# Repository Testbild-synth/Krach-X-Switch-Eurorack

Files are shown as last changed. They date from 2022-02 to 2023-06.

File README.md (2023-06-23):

# Krach X-Switch Eurorack Performance Module

Recently, I was commissioned by [Krach der Roboter](https://www.facebook.com/KrachDerRoboter/) who had the idea to design a passive performance tool based on the idea of quickly switching signal paths. What came out of it is this simple and useful module:

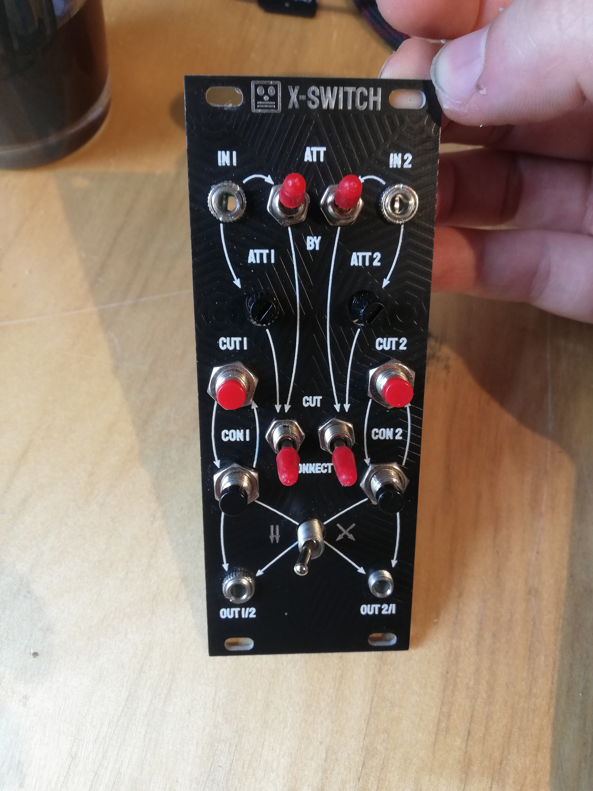
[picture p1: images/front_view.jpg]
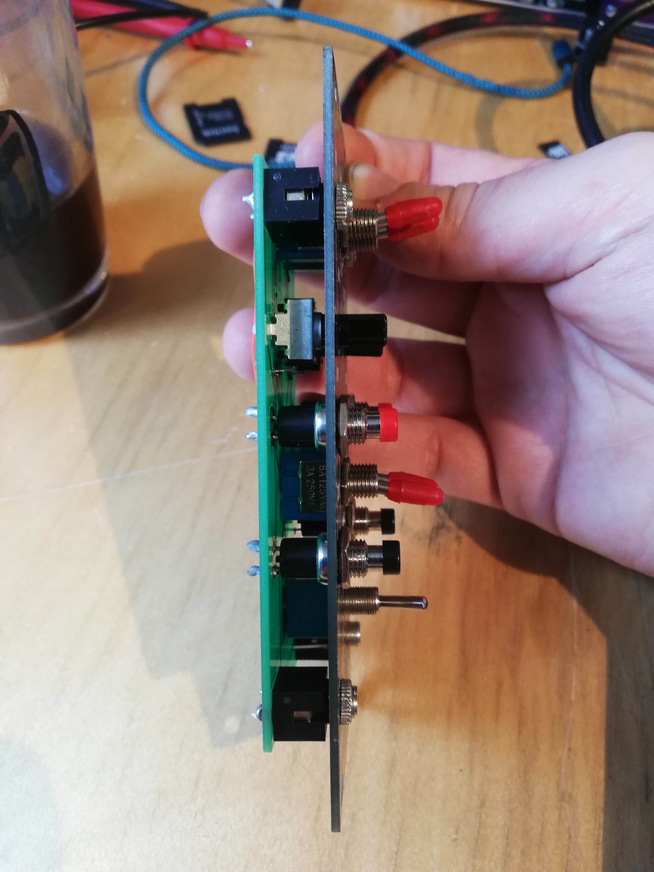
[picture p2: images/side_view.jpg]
 

## Status: recently added version 1.3 which has improved spacing for cut/connect switch legs

## Function

The core function of the module revolves around the "cross-switch". Two input channels are attenuated independently and then go to the output, but if you flip the cross switch, the Input 1 goes into output 2 and vice versa. This allows for fast back and forth switching of cv signals.
Additional pushbuttons can be used to cut or connect a lane. Spacing between components is rather large to allow his robot hands to reach everything easily.

This is also meant as an absolute beginner/first DIY module, so everything is made to be very easy to solder and all the traces are rather large so nothing gets damaged.

## PCB and Hardware

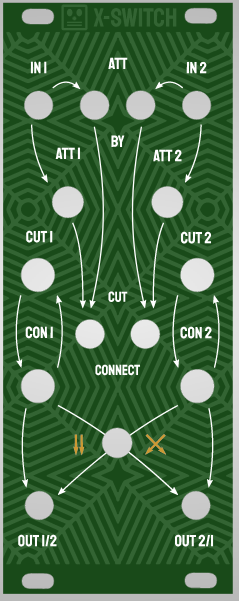
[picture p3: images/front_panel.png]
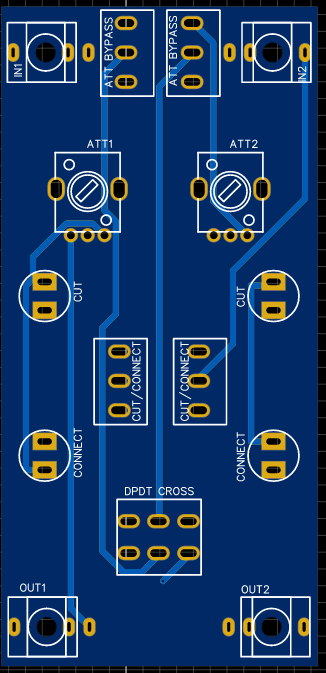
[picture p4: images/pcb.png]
 

You can find the schematic and BOM in the root folder.
For the PCBs, the module has one circuit PCB and one panel PCB. 
You can order them on any common PCB manufacturing service, we used [JLCPCB](https://jlcpcb.com/).

Standard settings should be fine, but as there is exposed copper on the panel you should go with a lead free surface finish (ENIG/Leadfree HASL).
If the panel sizes are not recognized correctly (may happen with my export sometimes) just put 128.5x50mm.

For the push switches, we used these, but you can use any that will somewhat fit the footprint and have <m7 thread on the top.
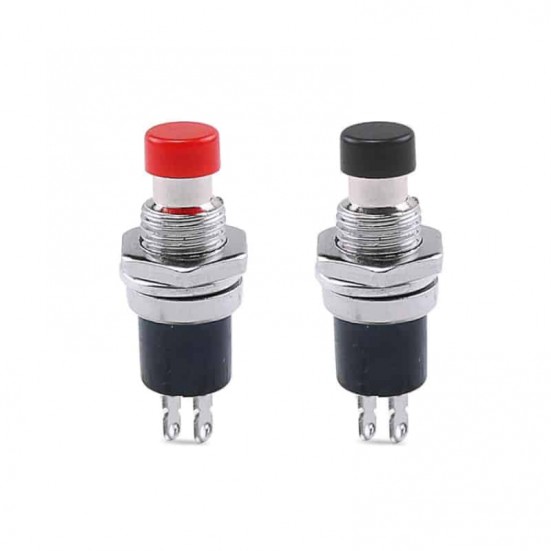
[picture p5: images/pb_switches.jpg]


## Assembly
Should be very straight forward, as always it is best to mount the components on the panel first before soldering so that they are properly in place.

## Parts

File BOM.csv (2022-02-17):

Name | Designator | Quantity
R09k Potentiometer, 100k Ohm | ATT1,ATT2 | 2
THONKICONN JACK | J1-J4 | 4
Pushbutton switch | PB1-PB4 | 4 | We used some like these https://www.pcboard.ca/mini-pushbutton, but there are probably a lot of others that fit
MTS-2 ON-ON switch 202 | SW1 | 1
MTS-1 ON-ON switch 102 | U1-U4 | 4

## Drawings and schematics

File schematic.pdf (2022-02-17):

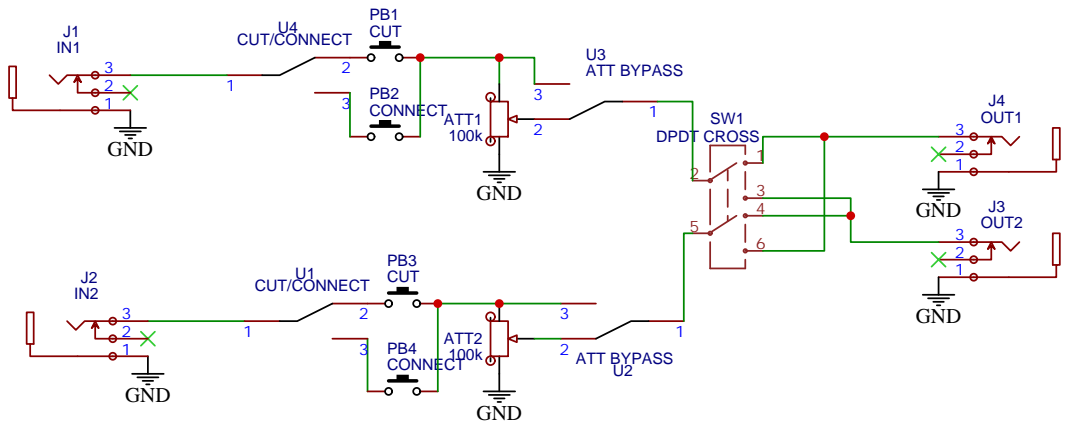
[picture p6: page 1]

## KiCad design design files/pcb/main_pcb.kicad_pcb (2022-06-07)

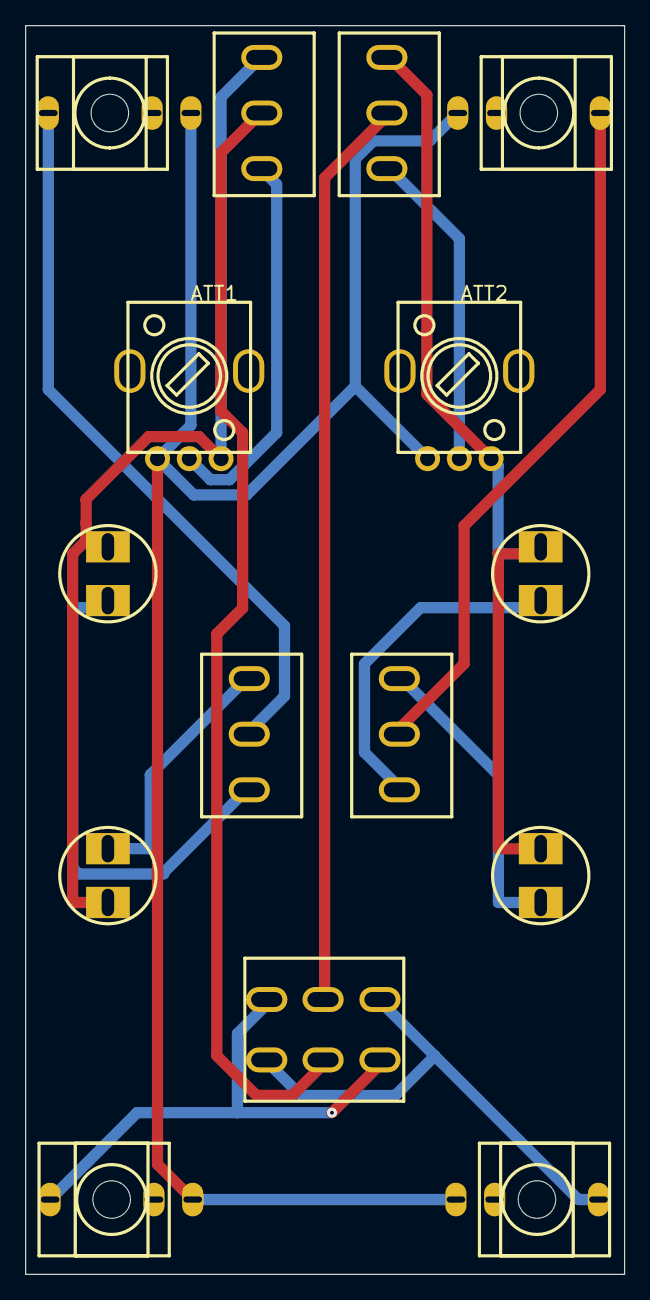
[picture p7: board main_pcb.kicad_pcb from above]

Board: 2 copper layers, 47.9 x 99.8 mm, 15 parts (0 on the bottom side), 15 nets.

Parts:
ATT1, ATT2: 100k; R09-5KΩ
J1: IN1; THONKICONN_1
J2: IN2; THONKICONN_1
J3: OUT1; THONKICONN_1
J4: OUT2; THONKICONN_1
PB1, PB3: CUT; PUSHBUTTON
PB2, PB4: CONNECT; PUSHBUTTON
SW1: DPDT CROSS; 6 PIN DPDT MOM SWITCH
U1, U4: CUT/CONNECT; MINI TOGGLE SWITCH SPDT ON-ON
U2, U3: ATT BYPASS; MINI TOGGLE SWITCH SPDT ON-ON

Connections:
ATT1_2: ATT1.2, U3.2
ATT2_2: ATT2.2, U2.2
GND: ATT1.1, ATT2.1, J1.1, J2.1, J3.1, J4.1
PB2_2: ATT1.3, PB1.2, PB2.2, U3.3
PB3_1: PB3.1, U1.2
PB3_2: ATT2.3, PB3.2, PB4.2, U2.3
PB4_1: PB4.1, U1.3
SW1_1: J4.3, SW1.1, SW1.6
SW1_2: SW1.2, U3.1
SW1_3: J3.3, SW1.3, SW1.4
SW1_5: SW1.5, U2.1
U1_1: J2.3, U1.1
U4_1: J1.3, U4.1
U4_2: PB1.1, U4.2
U4_3: PB2.1, U4.3

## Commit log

2022-02-17 upload gerbers and some design files
    [BOM.csv, stoiber.kicad_pcb]
2022-06-07 V1.2 small fix to pcb holes
    [circuit_pcb.kicad_pcb]
2023-06-06 v1_3 upload, better spacing for cut/connect switches
2023-06-23 v13 with slightly bigger holes
